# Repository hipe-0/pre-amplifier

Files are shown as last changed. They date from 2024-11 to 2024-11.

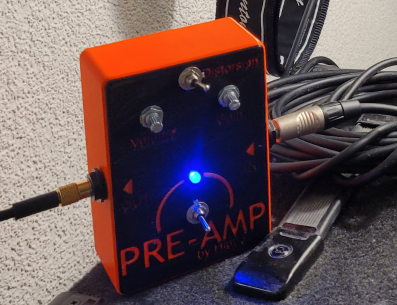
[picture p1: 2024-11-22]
oveview.png

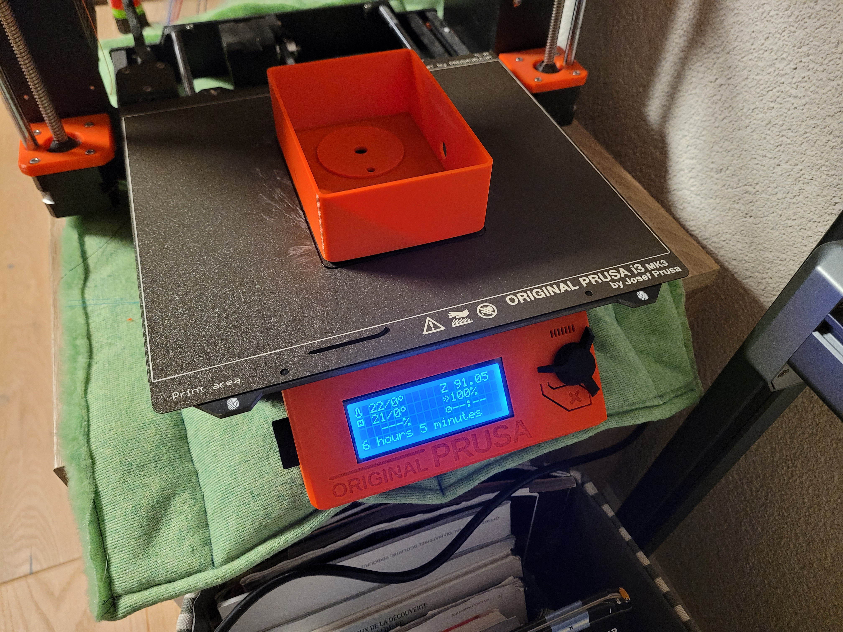
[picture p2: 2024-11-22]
media/20241118_070540.jpg

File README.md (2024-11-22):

# Pre-Amplifier by Hippo

This DIY amplifier brings nice overtones to my guitar or my DIY synthesizer (link on github https://github.com/hipe-0/synthesizer).
3D-Print (link on Thingiverse https://www.thingiverse.com/thing:6841592) and weld your own using the provided shematic and bill of materials!

This Guitar Amp is straightforward, it works and sounds great. Any feedback appreciated!

oveview

# Demo
https://github.com/user-attachments/assets/a7c7ef76-c136-456c-b7f8-a1a015e33860

# Features
1. Based on the simple **LM386** amplifier IC integrated circuit
 
3. **Volume** knob, **Gain** knob, **Saturation** switch, on/off switch
4. Nice smooth amplification volume from 0 to maximum
5. Nice ovetones after 80% of high gain knob
6. No preceptible audio noise or problem
7. **Distorsion** switch: For fun, I added simple clipping circuit using a single PNP transistor (S9012) 
8. Consequence on the oscilloscope, the upper part of the guitar signal is entirely chopped-off. A very drastic clipping stage! Side effect: it reduces volume a bit and cuts trailing reverbs of guitar as often the case, but it's nice.

# Shematic
2024-11-17 Guitar Amp with LM386 IC PCB version_schéma

# Prototype board view
2024-11-17 Guitar Amp with LM386 IC PCB version_bb

# PCB Printed circuit board (optional)
2024-11-17 Guitar Amp with LM386 IC PCB version_circuit imprimé

# Assembly


# Bill of material
- Enclosure box in PETG to print yourself (all 3D models are provided on this repository, a copy with printer settings is also on https://www.thingiverse.com/thing:6841592)
- Enclosure lid in PETG
- 4x PCB supports (to screw and glue)
- Either the printed PCB (gerber files are provided) or a prototype circuit board to weld yourself
- Wire
- 2x 6.5mm audio jack connectors (I used https://www.aliexpress.com/item/1005004458769152.html?spm=a2g0o.order_list.order_list_main.473.33de1802eYvuy3)
- IC LM386 operational amplificator
- PNP transistor S9012
- Blue LED 5mm
- Resistor 10K
- Resistor 1K
- Resistor 10 Ohm
- 2x Capacitors 0.47 mF
- 1x Capacitor 4.7 uF
- 2x Capacitor 10 uF
- 2x Potentiometer 10K with caps
- 18650 Li-ion battery with battery holder and 5v converter - charger (I used https://www.aliexpress.com/item/1005001621882169.html?spm=a2g0o.order_list.order_list_main.233.33de1802eYvuy3)

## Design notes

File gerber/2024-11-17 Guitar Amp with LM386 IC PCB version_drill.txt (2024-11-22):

; NON-PLATED HOLES START AT T1
; THROUGH (PLATED) HOLES START AT T100
M48
INCH
T1C0.125984
T100C0.038000
T101C0.032000
T102C0.035000
%
T1
X022379Y001157
X001379Y001157
X001379Y007157
X022379Y007157
T100
X019379Y007157
X009379Y001157
X022379Y005157
X007379Y001157
X012379Y001157
X001379Y003157
X022379Y003157
X008379Y001157
X001379Y004157
X022379Y004157
X006379Y007157
X011379Y001157
X014379Y001157
X015379Y001157
X020379Y007157
X005379Y007157
T101
X009367Y006160
X009367Y003160
X011367Y003160
X011367Y006160
X010367Y003160
X010367Y006160
X008367Y006160
X008367Y003160
T102
X003379Y004157
X018379Y005157
X006379Y005157
X013379Y006157
X004379Y001157
X018379Y003157
X020379Y005157
X016379Y002157
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

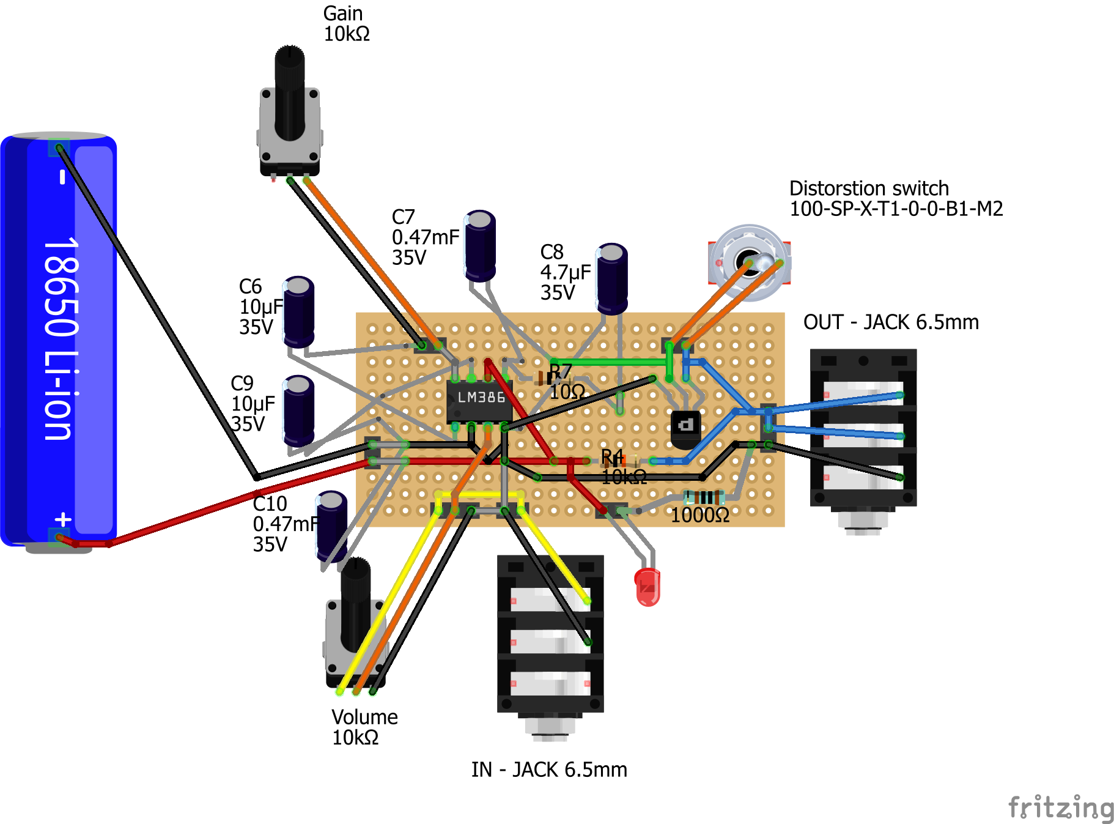
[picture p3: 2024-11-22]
2024-11-17 Guitar Amp with LM386 IC PCB version_bb.png

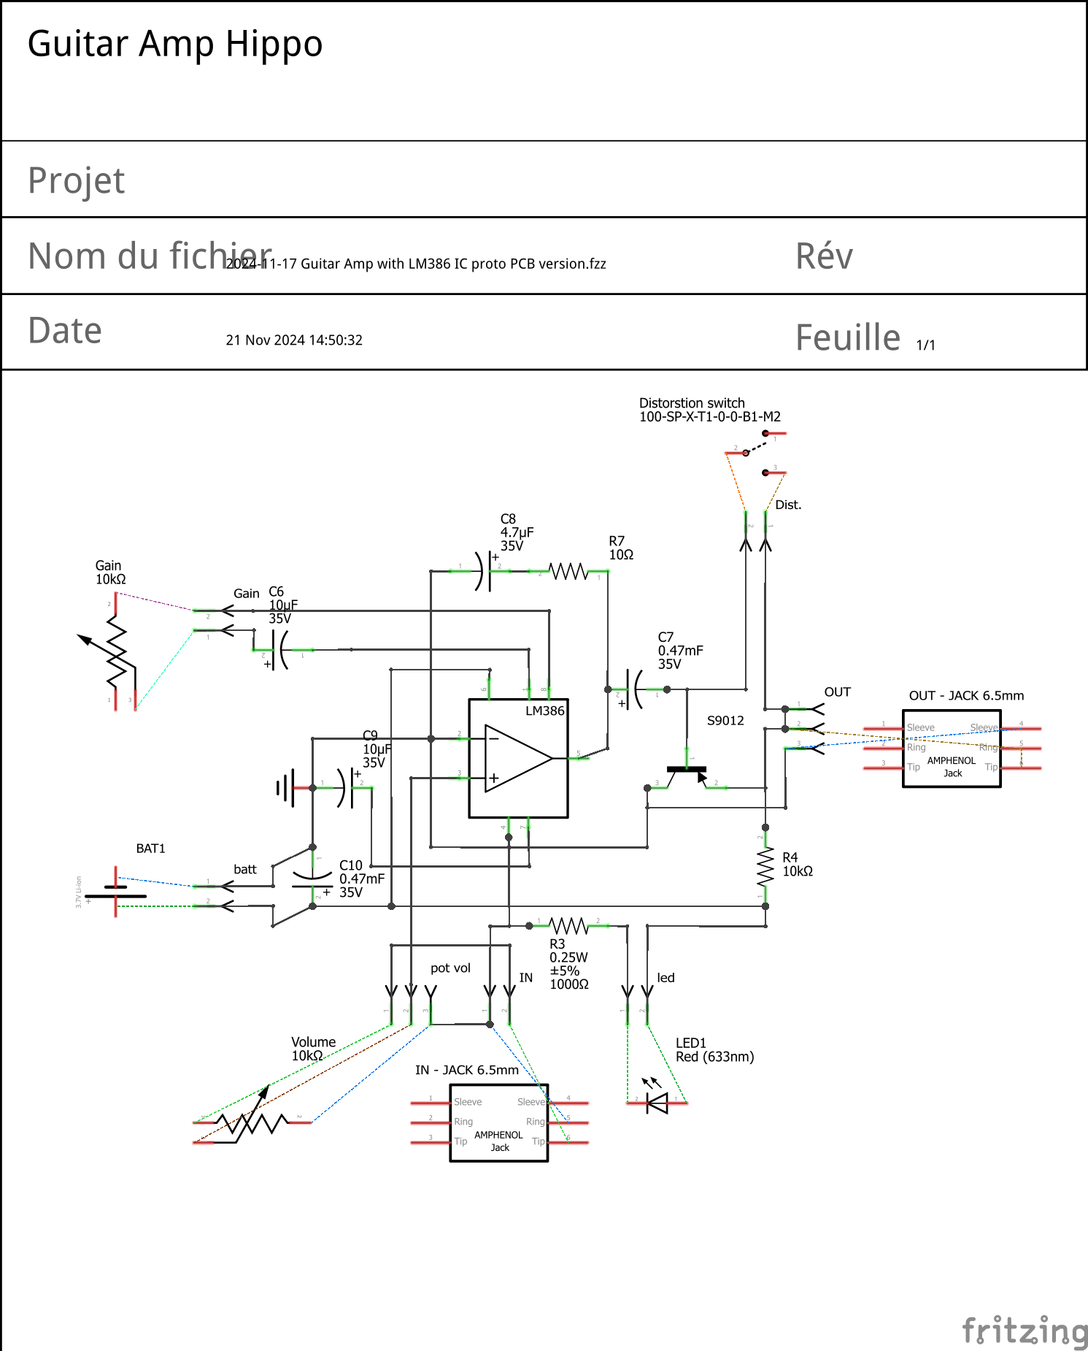
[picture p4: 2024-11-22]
2024-11-17 Guitar Amp with LM386 IC PCB version_schéma.png

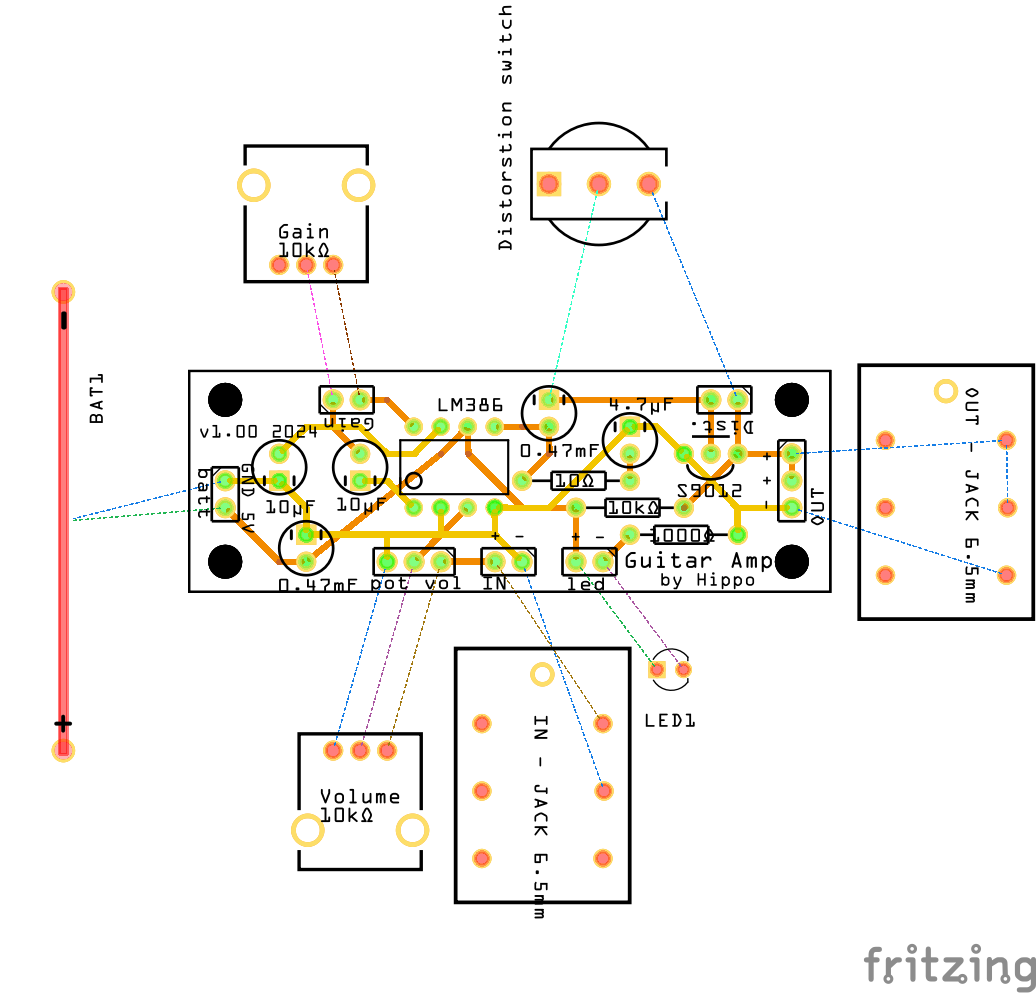
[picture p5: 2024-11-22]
2024-11-17 Guitar Amp with LM386 IC PCB version_circuit imprimé.png

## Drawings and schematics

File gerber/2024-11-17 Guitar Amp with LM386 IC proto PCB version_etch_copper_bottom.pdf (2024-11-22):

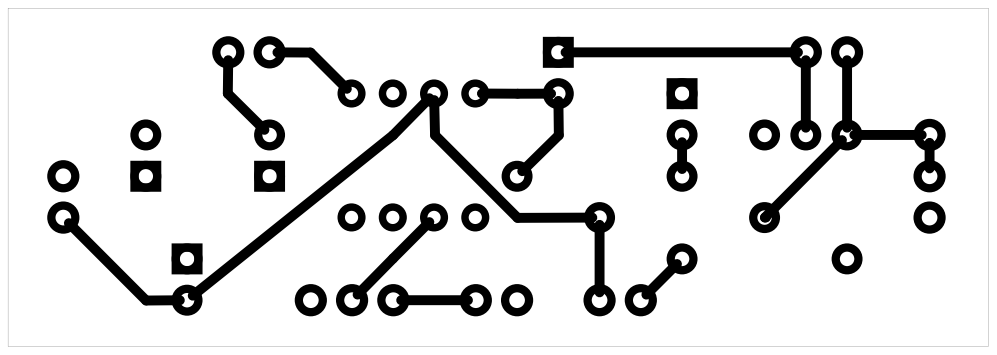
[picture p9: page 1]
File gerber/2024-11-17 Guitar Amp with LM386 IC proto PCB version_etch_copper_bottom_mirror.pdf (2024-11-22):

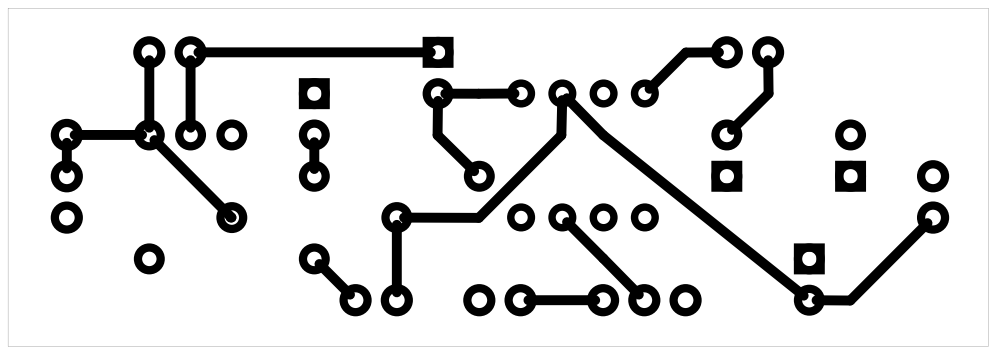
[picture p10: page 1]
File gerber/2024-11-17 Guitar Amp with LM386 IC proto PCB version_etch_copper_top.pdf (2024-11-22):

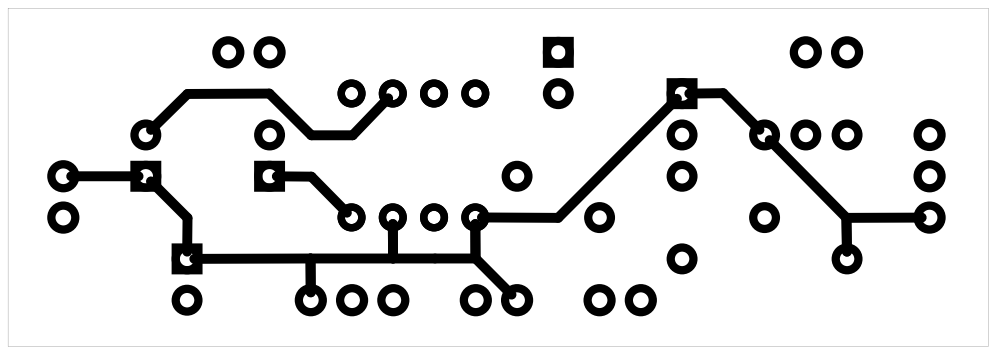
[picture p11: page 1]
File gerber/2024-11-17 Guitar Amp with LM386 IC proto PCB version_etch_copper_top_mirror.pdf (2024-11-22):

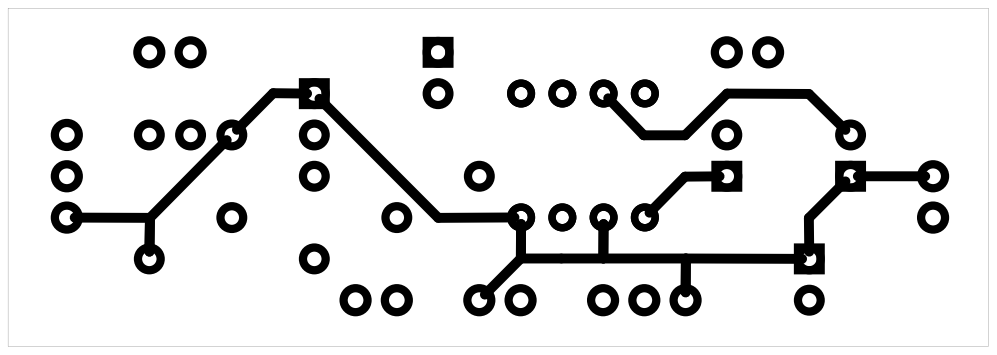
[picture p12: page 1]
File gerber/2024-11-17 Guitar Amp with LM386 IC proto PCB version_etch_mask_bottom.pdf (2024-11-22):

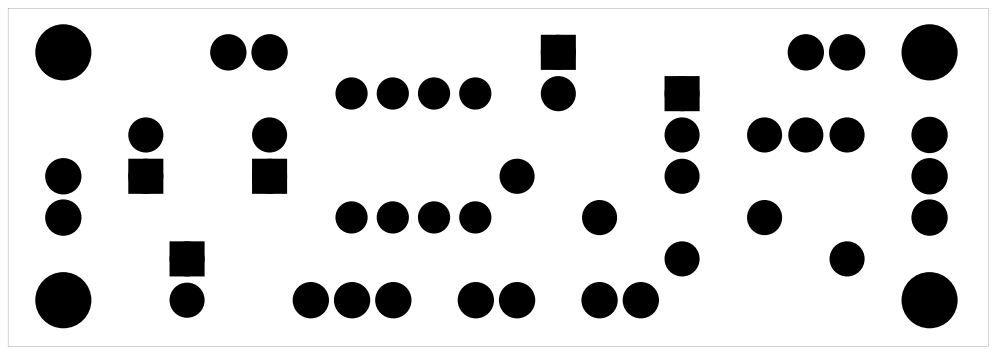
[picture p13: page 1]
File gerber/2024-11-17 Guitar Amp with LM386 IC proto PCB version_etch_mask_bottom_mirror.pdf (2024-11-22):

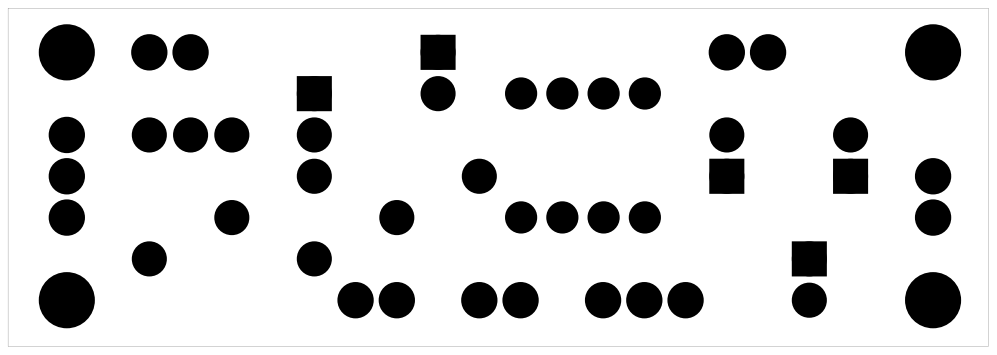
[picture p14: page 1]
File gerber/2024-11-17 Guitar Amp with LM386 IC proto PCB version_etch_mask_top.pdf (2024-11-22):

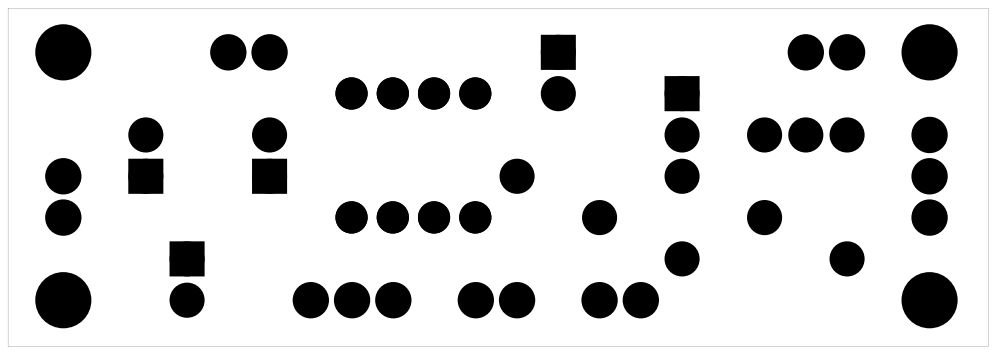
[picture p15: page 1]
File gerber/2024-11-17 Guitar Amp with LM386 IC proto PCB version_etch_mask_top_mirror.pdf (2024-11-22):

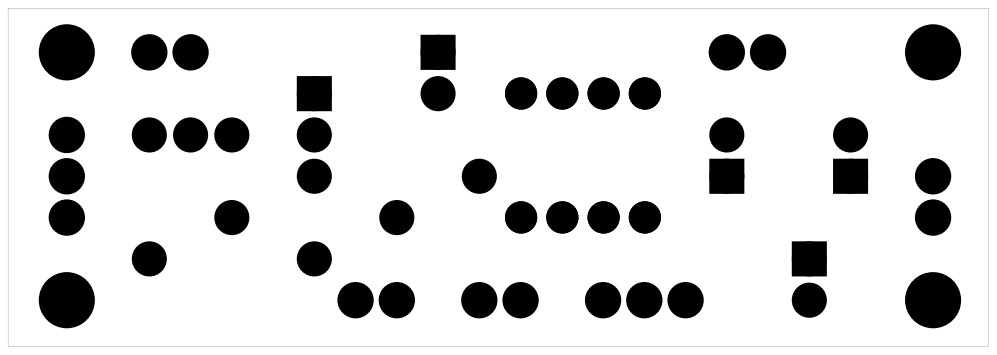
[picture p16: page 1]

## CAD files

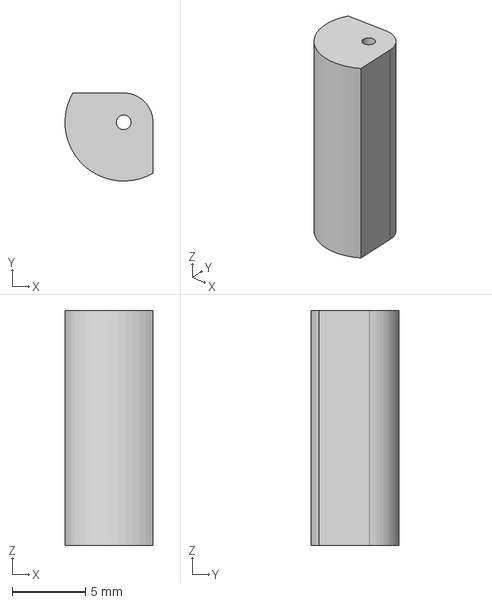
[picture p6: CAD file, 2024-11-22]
3Dprint/PCB support v8.step
6.00 x 6.00 x 16.0 mm

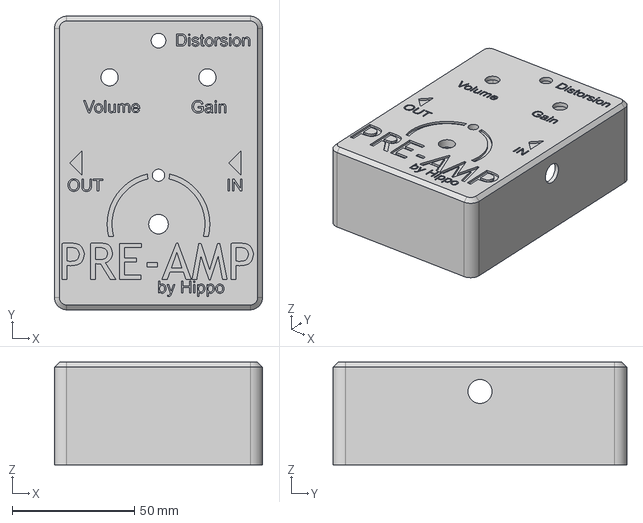
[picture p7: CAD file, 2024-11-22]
3Dprint/stompbox v7.step
85.0 x 120.0 x 42.0 mm

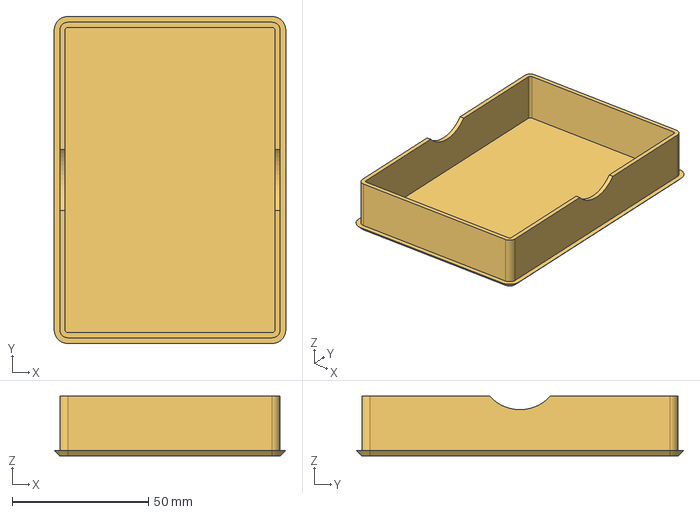
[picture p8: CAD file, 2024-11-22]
3Dprint/couvercle v10.step
85.0 x 120.0 x 22.0 mm
